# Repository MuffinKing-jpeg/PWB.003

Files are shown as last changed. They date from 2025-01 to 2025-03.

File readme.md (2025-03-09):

# PWB.003

PCB for powering something from 1S LI-PO or USB.  
Uses PMIC with integrated power mux.

Schematics: [Schematics](plots/PWB.003.pdf)  
Mechanical: [Mechanical](plots/PWB.003__Assembly.pdf)  
BOM: [BOM](production/bom.csv)

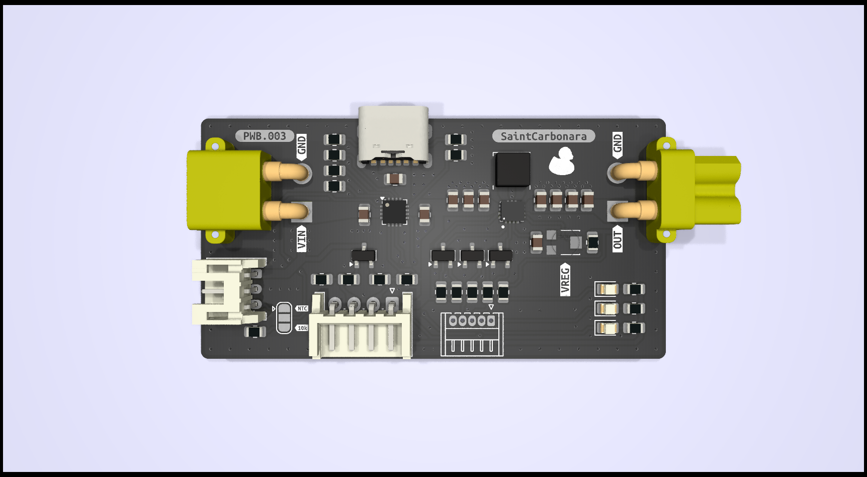
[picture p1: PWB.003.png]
top view of pcb

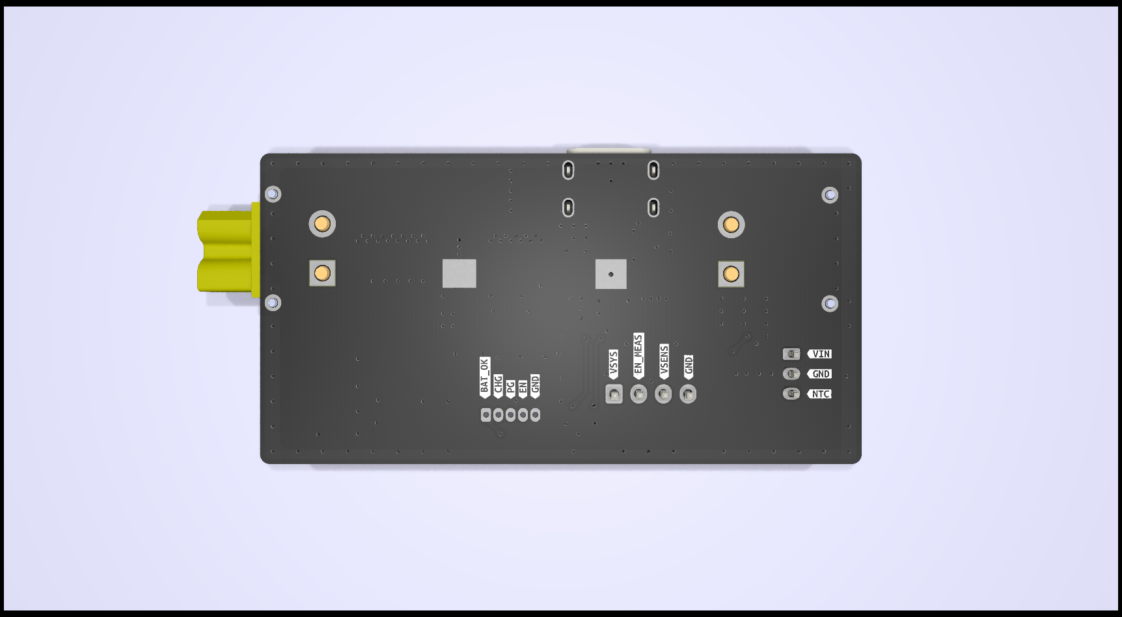
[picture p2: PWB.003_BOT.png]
bottom view of pcb


## Key features

- Configurable output
- Up to 3.5A input
- 2.5v\<VOUT\<16v
- Battery charging and protection
- low quiescent power consumption (In theory, still not tested)
- OVP, OCP, UVP (as claimed in datasheet for BQ24073RGT)

## Connectors

- 5x1 P1.25 for control communication with MCU
- 1x4 P2.54 for powering directly from BMS and measuring battery voltage
- 1x3 P2.00 for connecting LI-PO
- XT30 for input from battery
- XT30 for output after buck-bust
- USB-C for charging

## Key components

- BQ24073RGT
- TPS63070RNMR

## Test results

TBD

## Photos

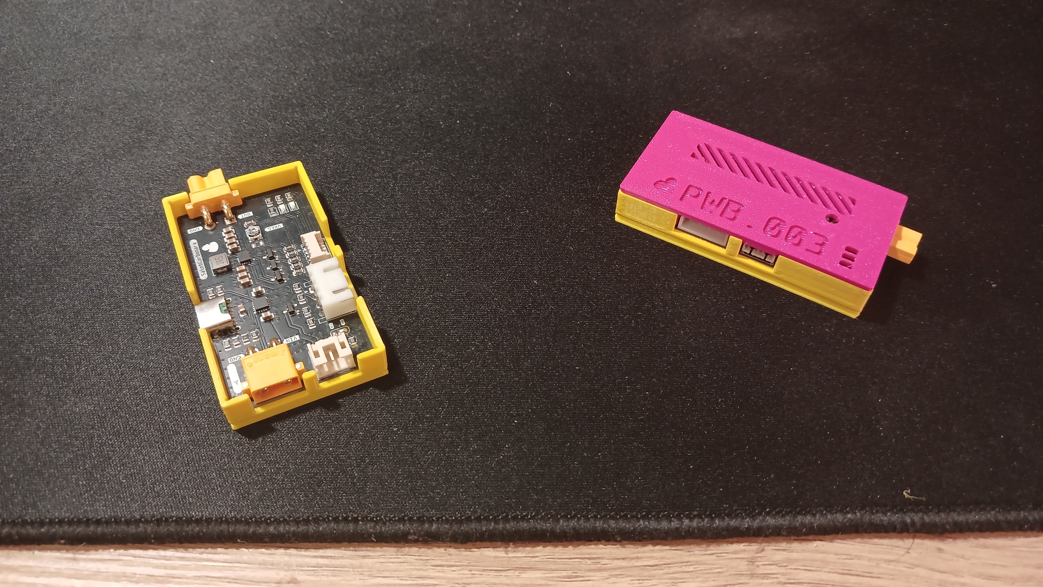
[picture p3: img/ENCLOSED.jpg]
photo of pcb inside enclosure

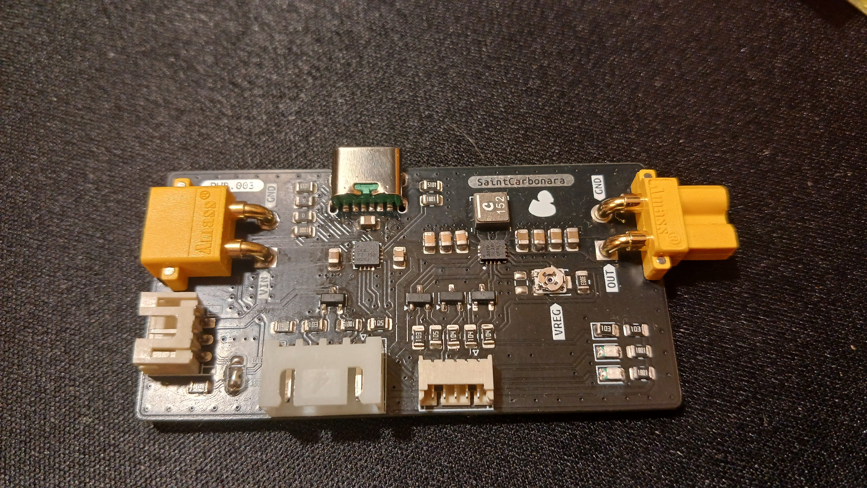
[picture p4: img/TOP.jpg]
top photo of pcb

bottom photo of pcb

## Disclaimer

This hardware design is provided "as is", without warranty of any kind, express or implied, including but not limited to the warranties of merchantability, fitness for a particular purpose, or noninfringement. The authors are not responsible for any damages, losses, or issues caused by the use of this design.

You are responsible for ensuring that the design complies with local regulations, safety standards, and any applicable laws.

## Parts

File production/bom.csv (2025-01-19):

Designator | Footprint | Quantity | Value | LCSC Part #
C1, C10, C9 | 0805 | 3 | 4.7u
C11 | 0805 | 1 | 100n
C2, C3, C4, C5 | 0805 | 4 | 10u
C6, C7, C8 | 0805 | 3 | 22u
D1 | 0805 | 1 | CNTRL_PG
D2 | 0805 | 1 | PMIC_PG
D3 | 0805 | 1 | CHRG
J1 | USB_C_Receptacle_GCT_USB4125-xx-x-0190_6P_TopMnt_Horizontal | 1 | USB_C_Receptacle_PowerOnly_6P | C456012
J2 | AMASS_XT30PW-F | 1 | XT30PW-F
J3 | AMASS_XT30PW-M | 1 | XT30PW-M
J4 | JST_PH_S3B-PH-K_1x03_P2.00mm_Horizontal | 1 | BAT | C5368765
J5 | JST_EH_S4B-EH_1x04_P2.50mm_Horizontal | 1 | Conn_01x04_Pin | C5341210
J6 | Hirose_DF13-05P-1.25DS_1x05_P1.25mm_Horizontal | 1 | Conn_01x05_Pin | C2689908
L1 | L_Coilcraft_XAL4020-XXX | 1 | 1.5uh | C3033018
Q1, Q2, Q4 | SOT-23 | 3 | IRLML6402TR | C347504
Q3 | SOT-23 | 1 | 2N7002 | C8545
R1, R2, R5 | 0805 | 3 | 5.1k
R10 | 0805 | 1 | 1k
R11, R14 | 0805 | 2 | 1M
R12, R18, R19, R4 | 0805 | 4 | 1.1k
R13, R20, R9 | 0805 | 3 | 10k
R15, R16, R17 | 0805 | 3 | 100k
R3 | 0805 | 1 | 0
R6 | 0805 | 1 | 3.3k
R7 | 0805 | 1 | 470k
R8 | 0805 | 1 | 33k
RV1 | Potentiometer_Bourns_TC33X_Vertical | 1 | 200k
U1 | VREG_TPS63070RNMR | 1 | TPS63070RNMR | C109322
U2 | VQFN-16-1EP_3x3mm_P0.5mm_EP1.6x1.6mm | 1 | BQ24073RGT | C15220

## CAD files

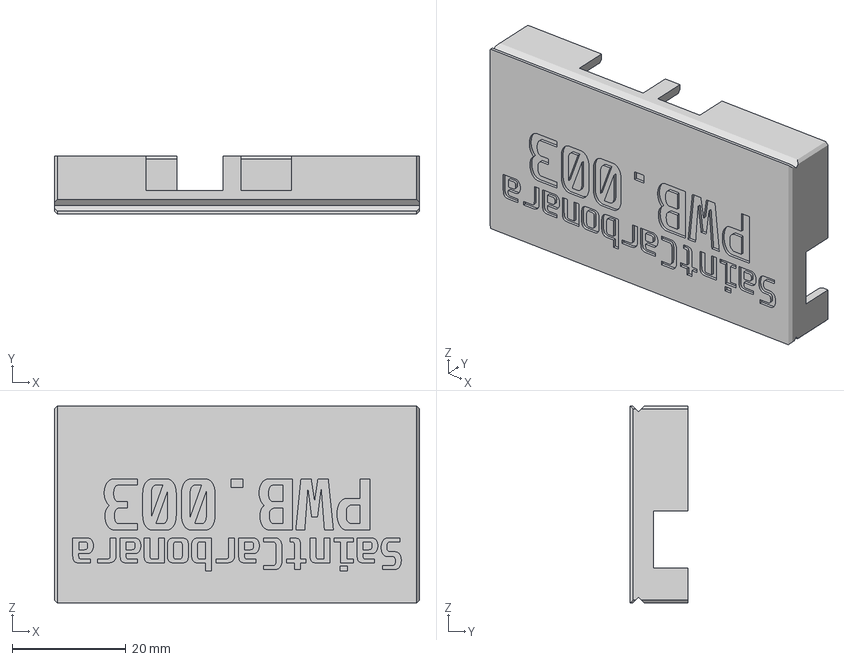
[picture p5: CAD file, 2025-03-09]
case/PWB.003_CASE_BOT.3mf
64.1 x 10.1 x 34.5 mm

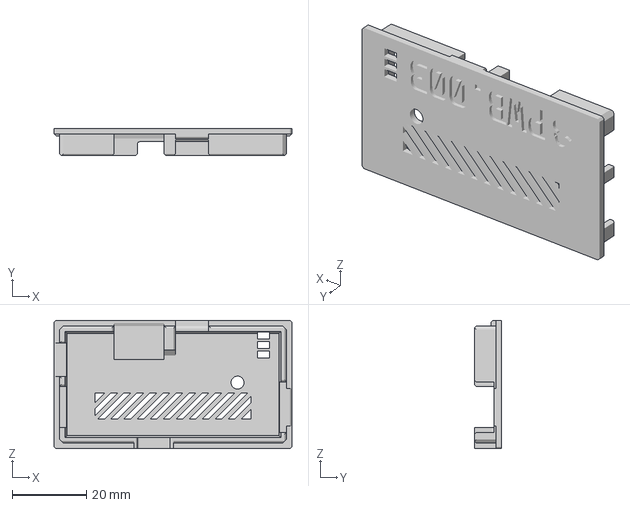
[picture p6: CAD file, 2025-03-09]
case/PWB.003_CASE_TOP.3mf
64.0 x 7.35 x 34.5 mm

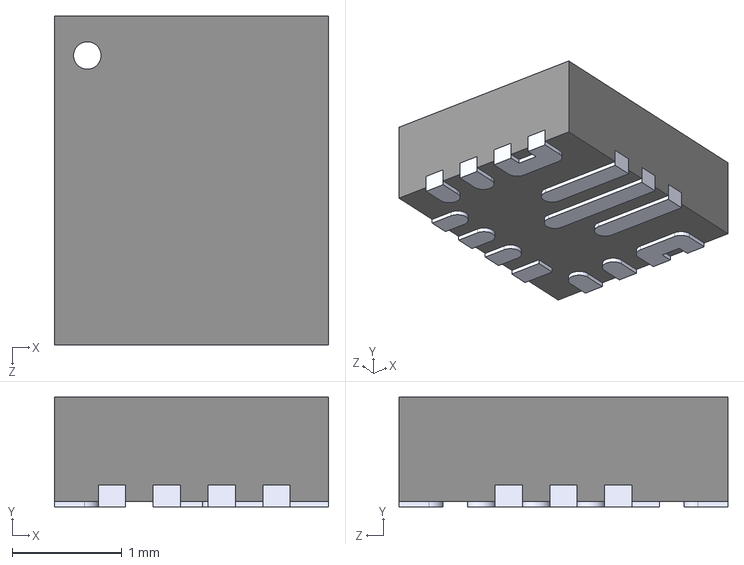
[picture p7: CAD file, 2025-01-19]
TPS63070RNMR/TPS63070RNMR.step
2.50 x 1.00 x 3.00 mm

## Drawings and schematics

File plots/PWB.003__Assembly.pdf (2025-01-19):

20,03 | mm | 13,8 mm
10,74 | mm 16,64 mm

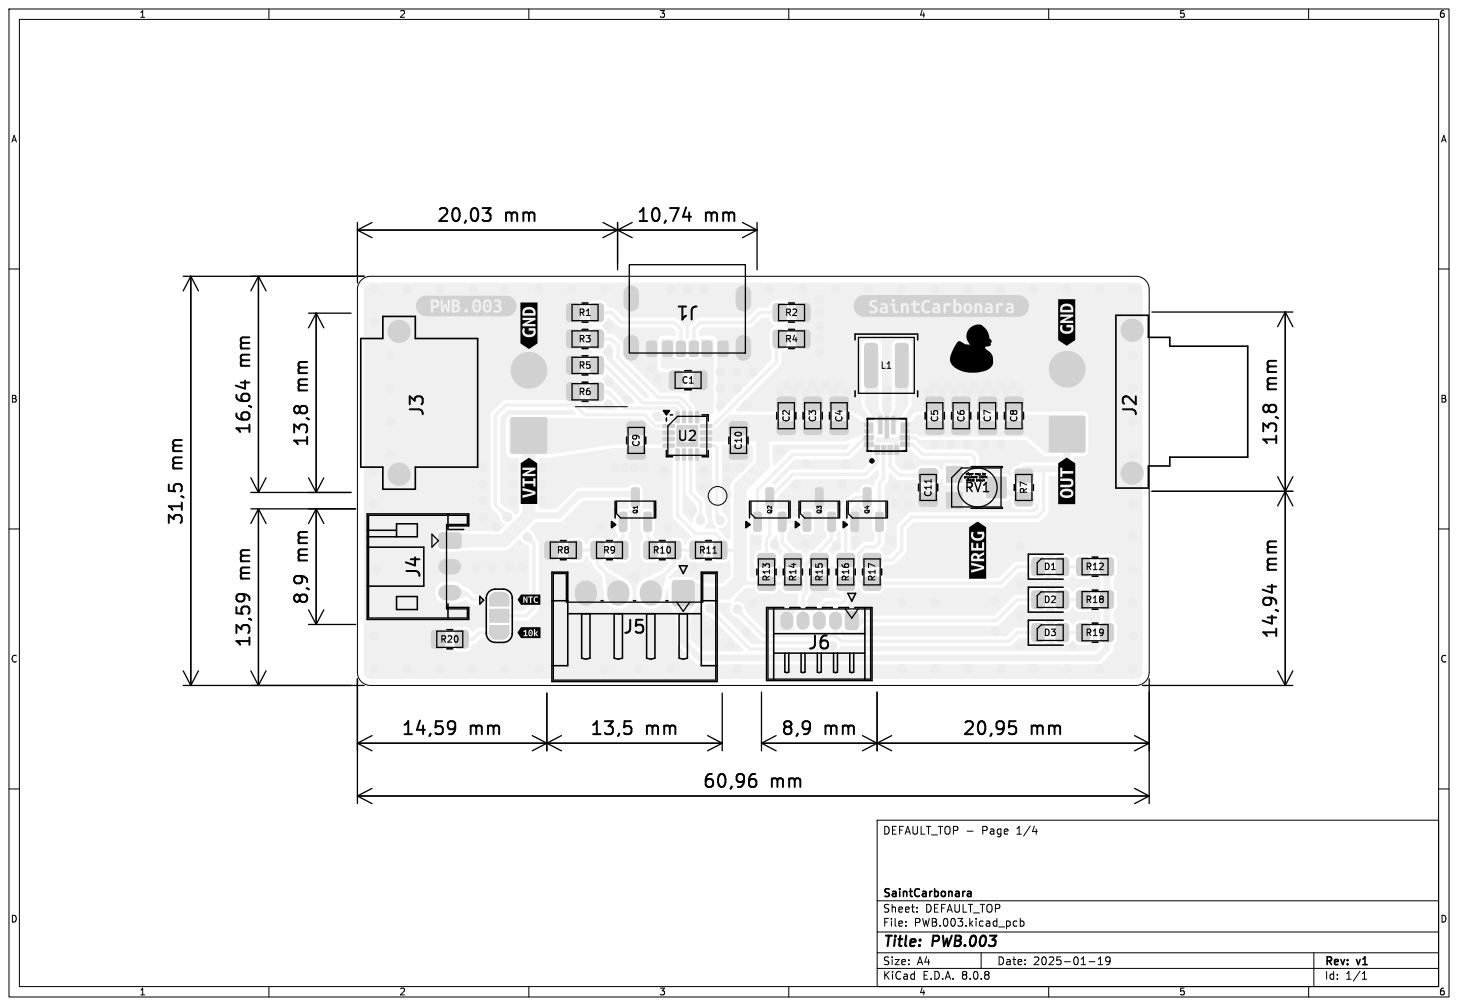
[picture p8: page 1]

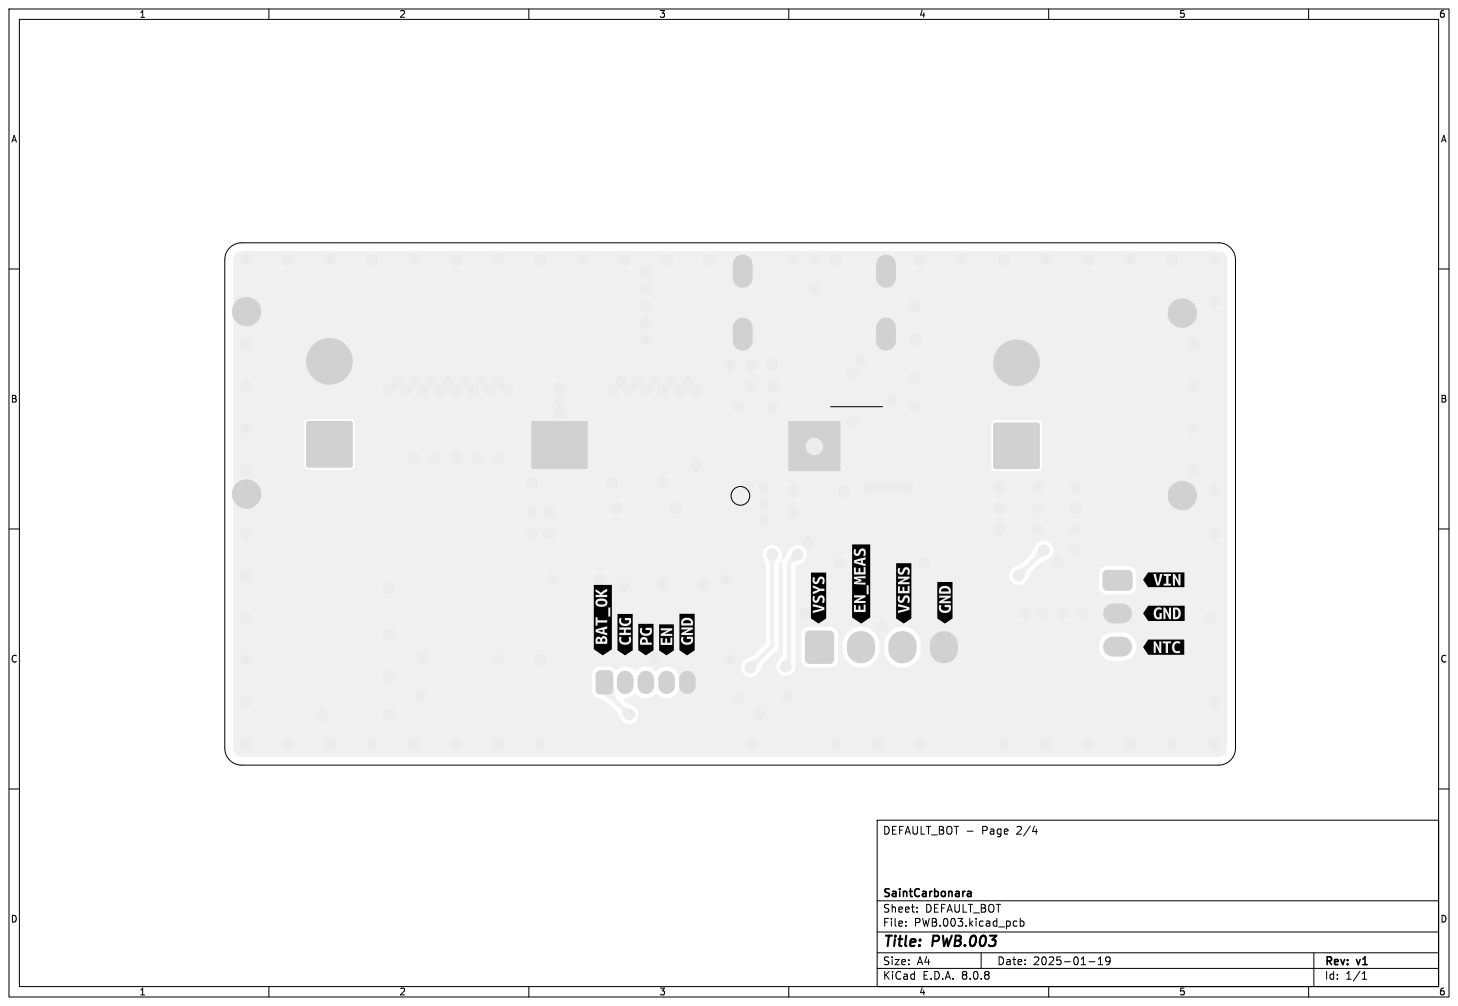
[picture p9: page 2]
D Date: 2025-01-19 KiCad; E.D.A. 8.0.8 Size: A4; Rev: v1; File: PWB.003.kicad_pcb Sheet: DEFAULT_BOT SaintCarbonara DEFAULT_BOT -; Page 2/4

Id: 1/1 Title: PWB.003

20,03 | mm | 13,8 mm
10,74 | mm 16,64 mm

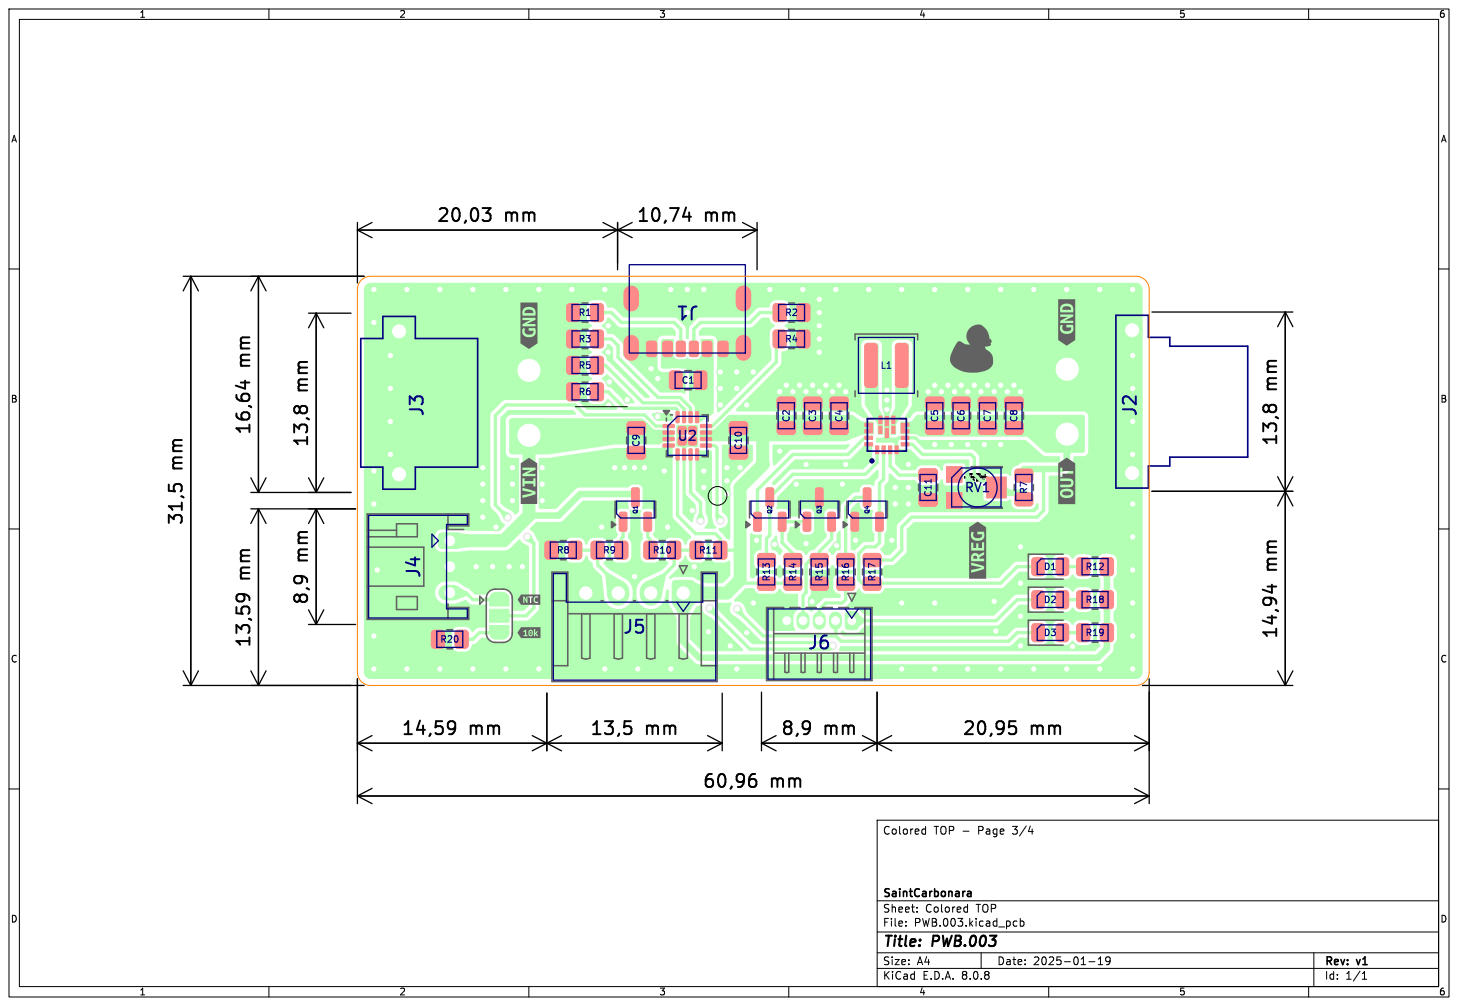
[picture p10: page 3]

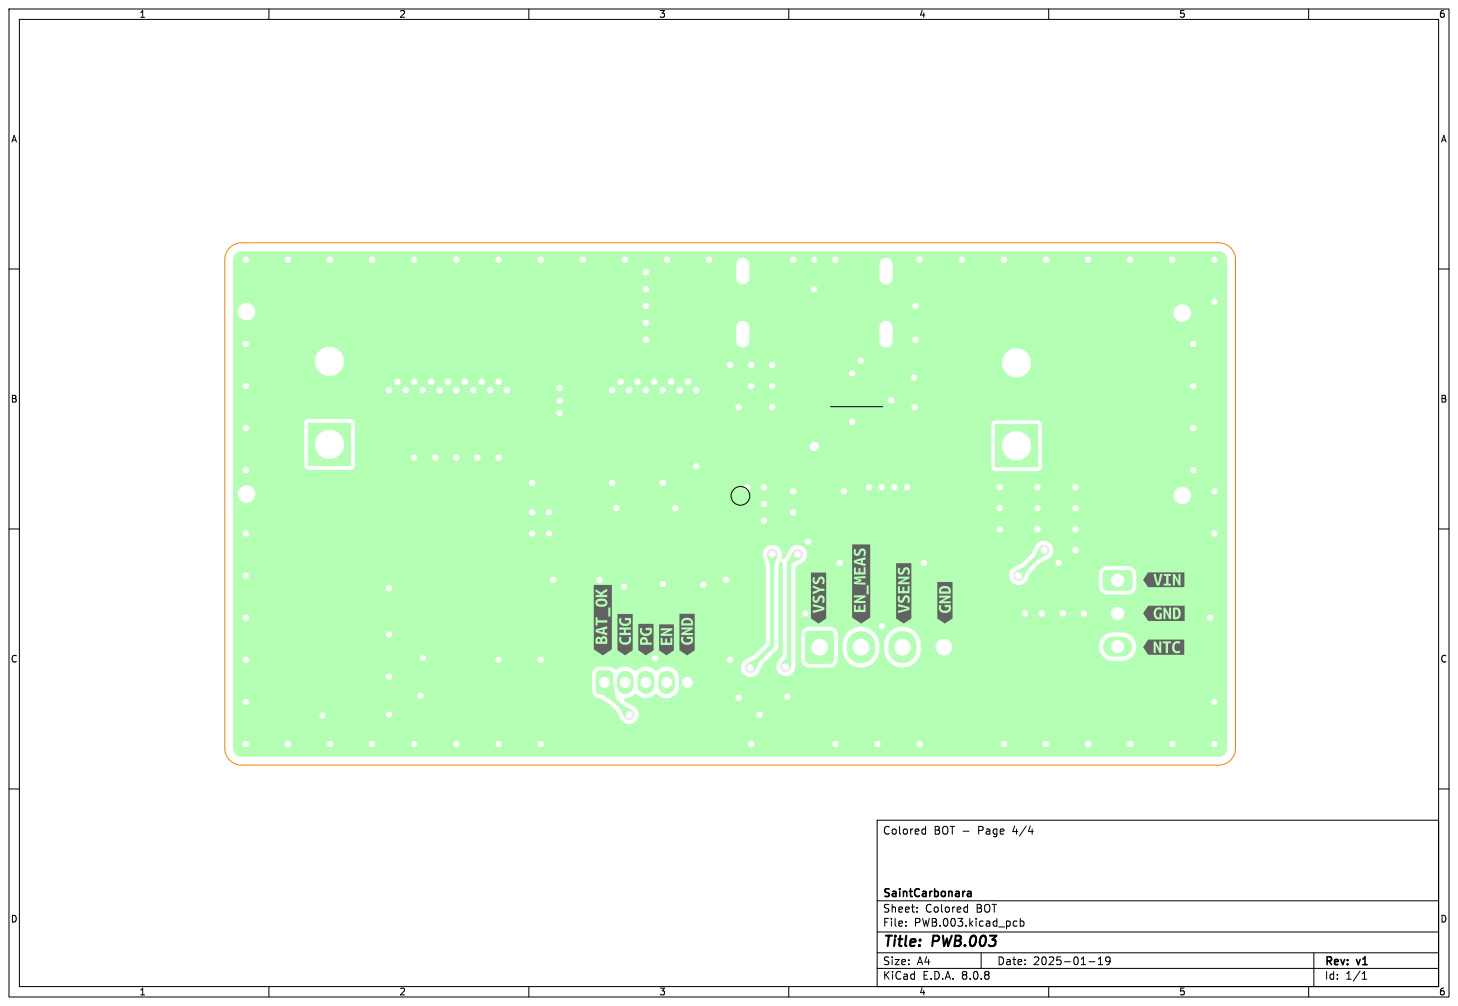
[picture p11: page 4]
D Date: 2025-01-19 KiCad; E.D.A. 8.0.8 Size: A4; Rev: v1; File: PWB.003.kicad_pcb Sheet: Colored; BOT SaintCarbonara Colored; BOT -; Page 4/4

Id: 1/1 Title: PWB.003

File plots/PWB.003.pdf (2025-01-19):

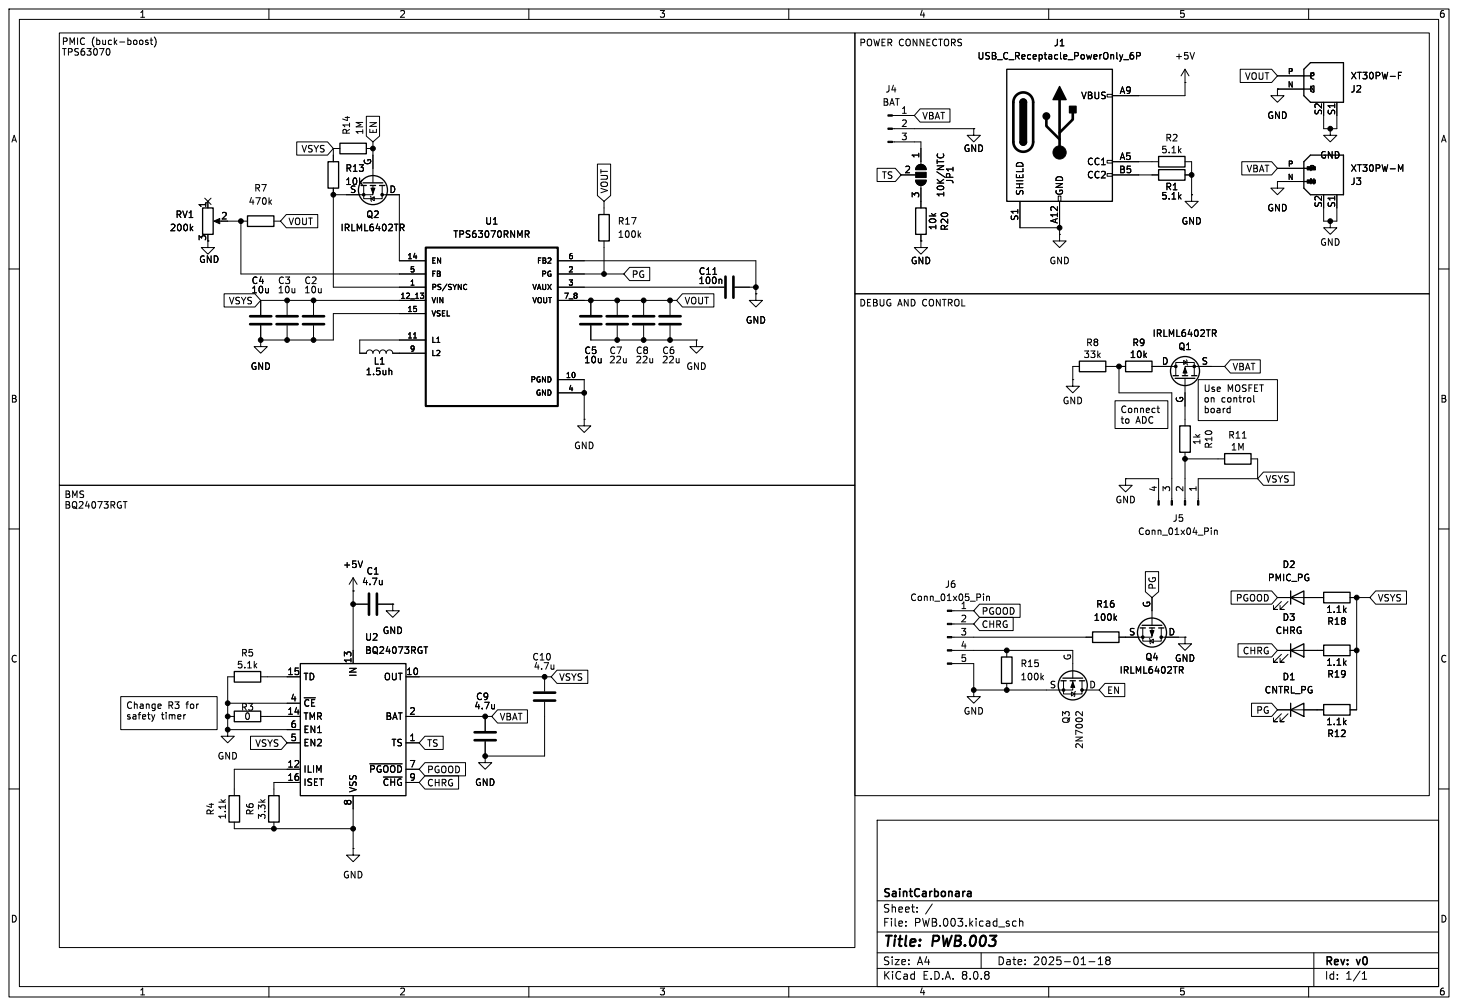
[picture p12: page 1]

File: PWB.003.kicad_sch Sheet: / SaintCarbonara GND

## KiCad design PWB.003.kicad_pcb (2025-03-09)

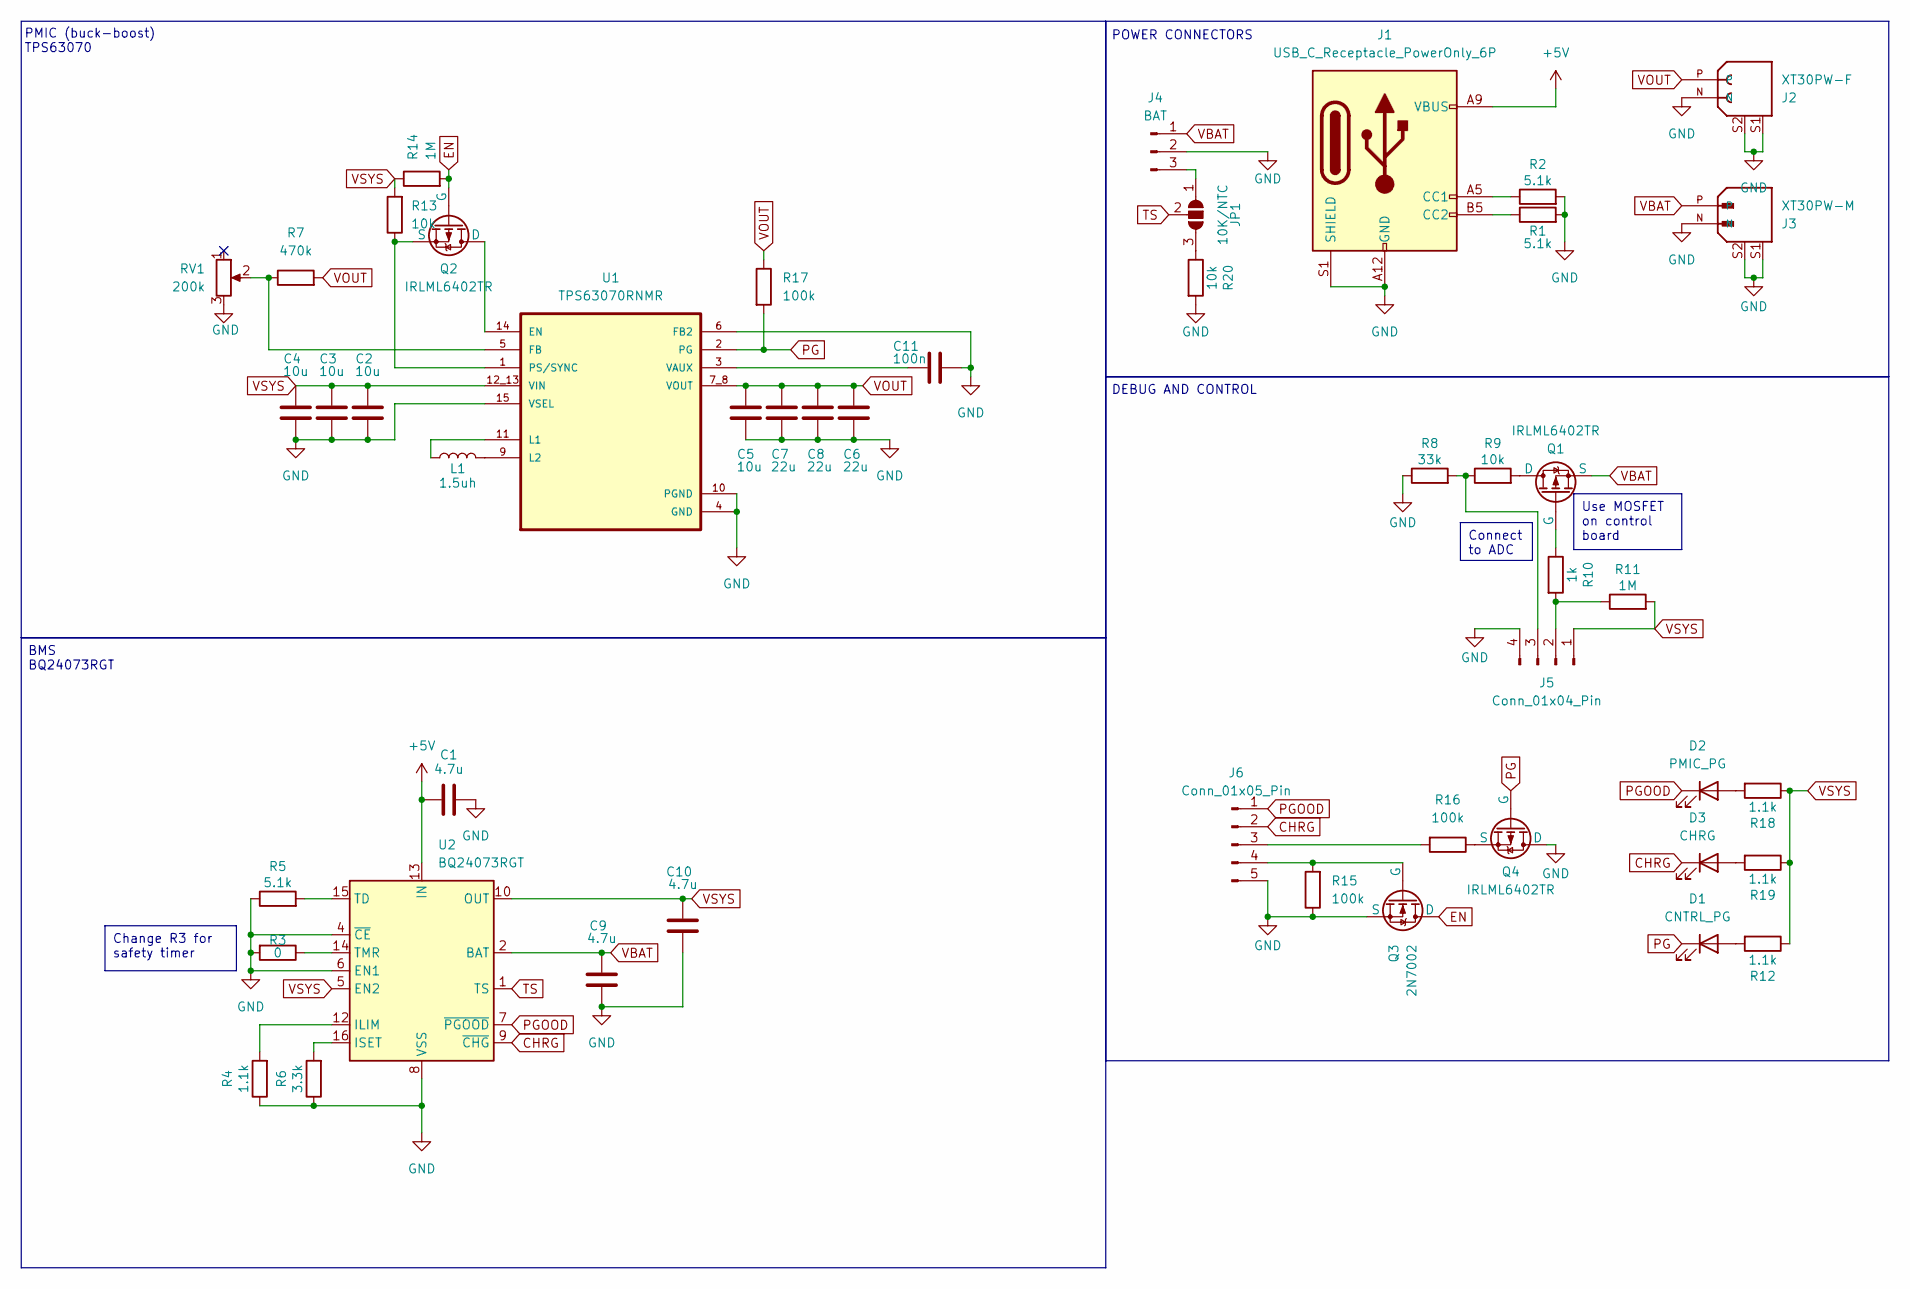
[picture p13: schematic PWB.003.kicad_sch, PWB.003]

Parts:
C1, C9, C10: 4.7u; C_0805_2012Metric
C2, C3, C4, C5: 10u; C_0805_2012Metric
C6, C7, C8: 22u; C_0805_2012Metric
C11: 100n; C_0805_2012Metric
D1: CNTRL_PG; LED_0805_2012Metric
D2: PMIC_PG; LED_0805_2012Metric
D3: CHRG; LED_0805_2012Metric
J1: USB_C_Receptacle_PowerOnly_6P; USB_C_Receptacle_GCT_USB4125-xx-x-0190_6P_TopMnt_Horizontal; LCSC C456012
J2: XT30PW-F; AMASS_XT30PW-F; PARTREV 1.2
J3: XT30PW-M; AMASS_XT30PW-M; PARTREV 1.2
J4: BAT; JST_PH_S3B-PH-K_1x03_P2.00mm_Horizontal; LCSC C5368765
J5: Conn_01x04_Pin; JST_EH_S4B-EH_1x04_P2.50mm_Horizontal; LCSC C5341210
J6: Conn_01x05_Pin; Hirose_DF13-05P-1.25DS_1x05_P1.25mm_Horizontal; LCSC C2689908
JP1: 10K/NTC; SolderJumper-3_P1.3mm_Open_RoundedPad1.0x1.5mm
L1: 1.5uh; L_Coilcraft_XAL4020-XXX; LCSC C3033018
Q1, Q2, Q4: IRLML6402TR; SOT-23; LCSC C347504
Q3: 2N7002; SOT-23; LCSC C8545
R1, R2, R5: 5.1k; R_0805_2012Metric
R3: 0; R_0805_2012Metric
R4, R12, R18, R19: 1.1k; R_0805_2012Metric
R6: 3.3k; R_0805_2012Metric
R7: 470k; R_0805_2012Metric
R8: 33k; R_0805_2012Metric
R9, R13, R20: 10k; R_0805_2012Metric
R10: 1k; R_0805_2012Metric
R11, R14: 1M; R_0805_2012Metric
R15, R16, R17: 100k; R_0805_2012Metric
RV1: 200k; Potentiometer_Bourns_TC33X_Vertical
U1: TPS63070RNMR; VREG_TPS63070RNMR; LCSC C109322
U2: BQ24073RGT; VQFN-16-1EP_3x3mm_P0.5mm_EP1.6x1.6mm; LCSC C15220

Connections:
+5V: C1.2, J1.A9 (VBUS), J1.B9 (VBUS), U2.13 (IN)
CHRG: D3.1 (K), J6.2, U2.9 (~CHG)
EN: Q2.2 (G), Q3.1 (D), R14.2
GND: C1.1, C2.1, C3.1, C4.1, C5.1, C6.1, C7.1, C8.1, C9.1, C10.1, C11.2, J1.A12 (GND), J1.B12 (GND), J1.S1 (SHIELD), J2.N, J2.S1, J2.S2, J3.N, J3.S1, J3.S2, J4.2, J5.4, J6.5, Q3.3 (S), Q4.1 (D), R1.2, R2.2, R3.2, R4.1, R5.1, R6.1, R8.1, R15.1, R20.2, RV1.3, U1.4 (GND), U1.6 (FB2), U1.10 (PGND), U1.15 (VSEL), U2.4 (~CE), U2.6 (EN1), U2.8 (VSS), U2.17 (VSS)
unnamed: D1.2 (A), R12.2
unnamed: D2.2 (A), R18.2
unnamed: D3.2 (A), R19.2
unnamed: J1.A5 (CC1), R2.1
unnamed: J1.B5 (CC2), R1.1
unnamed: J4.3, JP1.1 (A)
unnamed: J5.2, R10.2, R11.1
unnamed: J5.3, R8.2, R9.1
unnamed: J6.3, R16.2
unnamed: J6.4, Q3.2 (G), R15.2
unnamed: JP1.3 (B), R20.1
unnamed: Q1.1 (D), R9.2
unnamed: Q1.2 (G), R10.1
unnamed: Q2.1 (D), U1.14 (EN)
unnamed: Q2.3 (S), R13.1, U1.1 (PS/SYNC)
unnamed: Q4.3 (S), R16.1
unnamed: R7.1, RV1.2, U1.5 (FB)
unnamed: L1.1, U1.11 (L1)
unnamed: L1.2, U1.9 (L2)
unnamed: C11.1, U1.3 (VAUX)
unnamed: R4.2, U2.12 (ILIM)
unnamed: R6.2, U2.16 (ISET)
unnamed: R5.2, U2.15 (TD)
unnamed: R3.1, U2.14 (TMR)
PG: D1.1 (K), Q4.2 (G), R17.2, U1.2 (PG)
PGOOD: D2.1 (K), J6.1, U2.7 (~PGOOD)
TS: JP1.2 (C), U2.1 (TS)
VBAT: C9.2, J3.P, J4.1, Q1.3 (S), U2.2 (BAT), U2.3 (BAT)
VOUT: C5.2, C6.2, C7.2, C8.2, J2.P, R7.2, R17.1, U1.7_8 (VOUT)
VSYS: C2.2, C3.2, C4.2, C10.2, J5.1, R11.2, R12.1, R13.2, R14.1, R18.1, R19.1, U1.12_13 (VIN), U2.5 (EN2), U2.10 (OUT), U2.11 (OUT)

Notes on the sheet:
Change R3 for safety timer
Use MOSFET on control board
Connect to ADC
BMS BQ24073RGT
POWER CONNECTORS
DEBUG AND CONTROL
PMIC (buck-boost) TPS63070

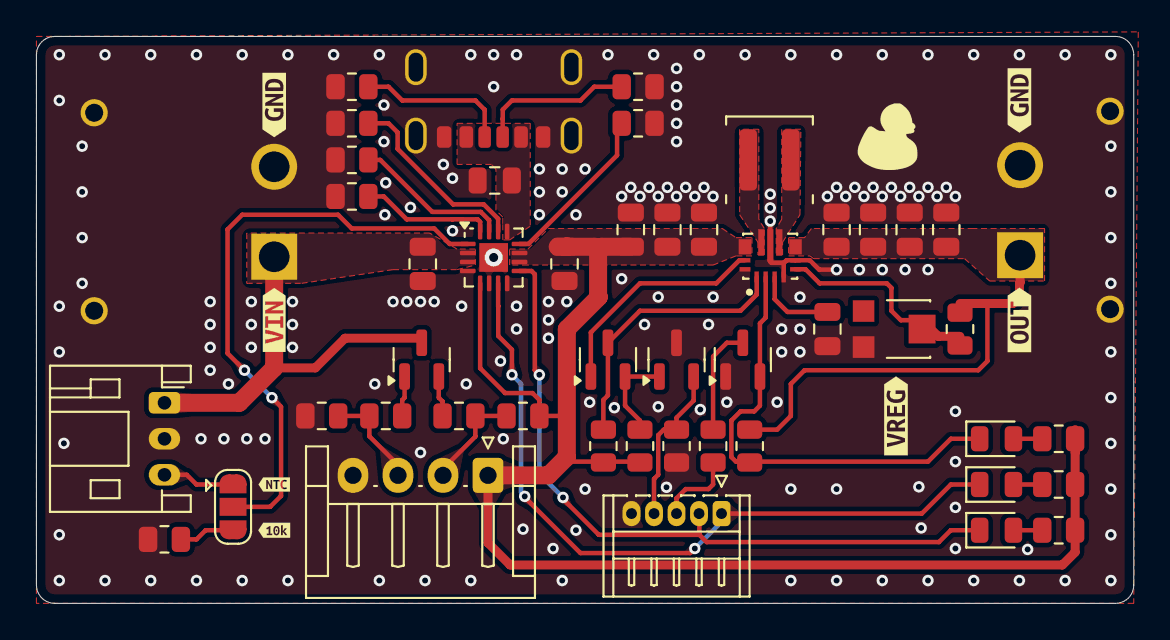
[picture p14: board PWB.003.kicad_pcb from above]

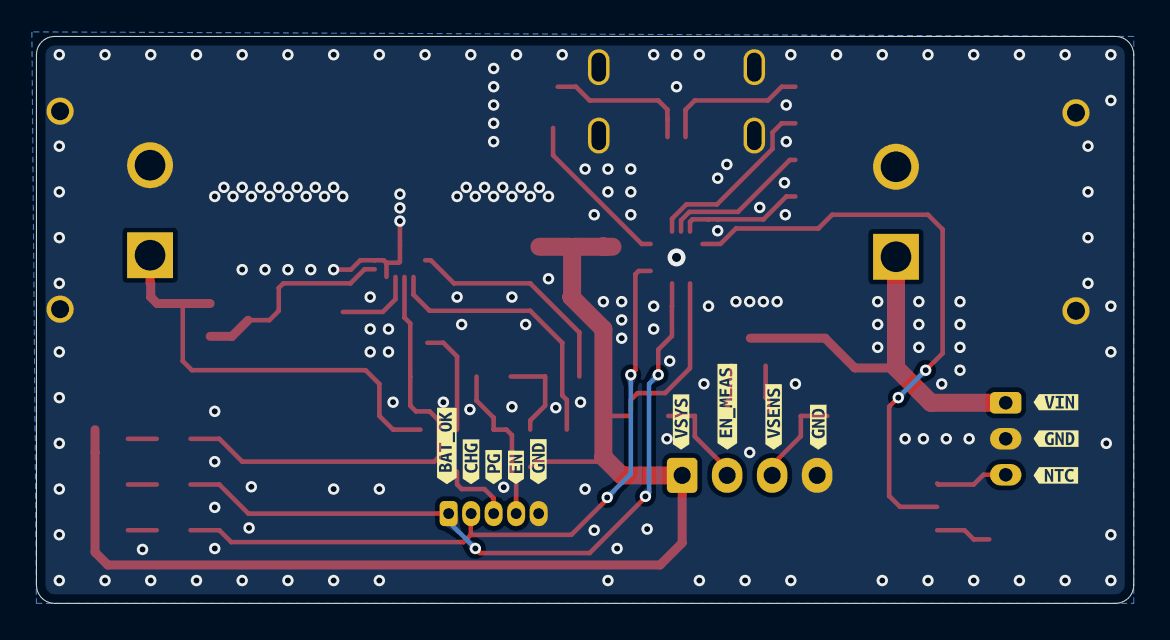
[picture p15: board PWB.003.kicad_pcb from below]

Board: 2 copper layers, 61.0 x 31.5 mm, 70 parts (12 on the bottom side), 34 nets.

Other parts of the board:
kibuzzard-1: G***; kibuzzard-678CDDCF
kibuzzard-2: G***; kibuzzard-678CDE28
kibuzzard-3: G***; kibuzzard-678CDB1C
kibuzzard-4: G***; kibuzzard-678CDC56
kibuzzard-5: G***; kibuzzard-678CDC37
kibuzzard-6: G***; kibuzzard-678CDC60
kibuzzard-7: G***; kibuzzard-678D5D09
kibuzzard-8: G***; kibuzzard-678CDEF3
kibuzzard-9: G***; kibuzzard-678CDEE7
kibuzzard-678D6AC8: G***; kibuzzard-678D6AC8
kibuzzard-678D6ACE: G***; kibuzzard-678D6ACE
kibuzzard-678D6AD4: G***; kibuzzard-678D6AD4
kibuzzard-678D6AE1: G***; kibuzzard-678D6AE1
kibuzzard-678D6AE6: G***; kibuzzard-678D6AE6
kibuzzard-678D6B1B: G***; kibuzzard-678D6B1B
kibuzzard-678D6B2C: G***; kibuzzard-678D6B2C
kibuzzard-678D6B8A: G***; kibuzzard-678D6B8A
kibuzzard-678D6B9C: G***; kibuzzard-678D6B9C
kibuzzard-678D6B21: G***; kibuzzard-678D6B21
kibuzzard-678D6B26: G***; kibuzzard-678D6B26
kibuzzard-678D6B93: G***; kibuzzard-678D6B93

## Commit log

2025-01-19 Init commit
    [PWB.003.kicad_pcb, PWB.003.kicad_sch, TPS63070RNMR.step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]
2025-01-19 Improved PCB
    - Added 10k resistor on control inputs TPS63070
    - Changed layout of inductor and filtering capacitors
    - added legend on bottom layer
    - updated DRC
    - validated design on JLCDFM
    [PWB.003.kicad_pcb, PWB.003.kicad_sch, bom.csv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]
2025-03-09 Updated info - added photos
    [PWB.003.kicad_pcb]
2025-03-09 Added case design files
    [PWB.003_CASE_BOT.3mf, PWB.003_CASE_TOP.3mf]
